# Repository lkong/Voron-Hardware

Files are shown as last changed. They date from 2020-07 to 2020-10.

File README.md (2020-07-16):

# Voron-Hardware
Cool Hardware designed by the Voron Design group

| Project | Overview |  
|---|---|
| Hall Effect Endstop | Replacement for mechanical endstop switches with an adjustable magnetic endstop PCB |
| Klipper Expander | Standalone MCU for use with Klipper with various inputs and outputs |
| Nano Display | Adapts an Arduino Nano to the RepRap standard 2 2x5pin IDC Connectors |
| Taco Raven | 3D Printer controller with 8 integrated stepper drivers for use with Klipper |
| Toolhead Board | Remix of Klipper Expander to fit on a toolhead mounted to a nema17 or 40mm fan |

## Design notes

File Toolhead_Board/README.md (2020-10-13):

# STM32-Tool-Heade-Board

Image no work =(

Simple MCU board for use with Klipper 3D Printer firmware with:
 - STM32F042F6P6 MCU with internal oscilator
 - 4 Mosfet outputs (1 3A one for hotend, 3 for fans)
 - 2 Thermistor inputs
 - 1 GPIO header

 Parts that need to be sourced if assembled by JLC:
  - Micro USB port [Molex 105017-0001](https://www.digikey.com/product-detail/en/molex/1050170001/WM1399CT-ND/2350885) or equivalent [Amazon](https://www.amazon.com/gp/product/B01IQ8VN94)
  - Resettable Fuse [MF-R800](https://www.digikey.com/en/products/detail/bourns-inc/MF-R800/259980)
  - 2 Pin Tactile Switch [6 x 3.5mm Button](https://www.digikey.com/product-detail/en/c-k/PTS636-SP43-LFS/CKN12304-ND/10071717) or [Amazon](https://www.amazon.com/flashtree-3x6x4-3H-Momentary-Tactile-Button/dp/B083R566PK/ref=sr_1_13)
  - Screw Terminals [5.08mm Screw Terminals](https://www.digikey.com/product-detail/en/on-shore-technology-inc/OSTTA024163/ED2580-ND/614529)

To flash:
  1 Bridge BOOT1 with solder
  2 Flash
  3 disconnect BOOT1

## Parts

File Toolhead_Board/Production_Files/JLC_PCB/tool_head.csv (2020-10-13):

Id | Designator | Package | Quantity | Designation | Supplier and ref
1 | R9,R7,R8,R10 | R_0805_2012Metric | 4 | 100
2 | U1 | TSSOP-20_4.4x6.5mm_P0.65mm | 1 | STM32F042F6Px
3 | BOOT1 | R_0805_2012Metric | 1 | 0R
4 | R1,R2,R11,R12,R13,R14 | R_0805_2012Metric | 6 | 10K
5 | C1,C3 | C_0805_2012Metric | 2 | 0.1uF
6 | C2,C4 | C_0805_2012Metric | 2 | 4.7uF
7 | C5,C6 | C_0805_2012Metric | 2 | 10uF
8 | D1,D2,D3,D4,D5,D6,D7 | LED_0805_2012Metric | 7 | LED
9 | J1 | USB_Micro-B_Molex-105017-0001 | 1 | USB_B_Micro
10 | J3 | PinHeader_2x04_P2.54mm_Horizontal | 1 | Conn_02x04_Odd_Even
11 | J5 | 1x02_ScrewTerminal_Phoenix | 1 | Vin
12 | J6 | 1x02_ScrewTerminal_Phoenix | 1 | HotEnd
13 | J8 | JST_XH_B2B-XH-AM_1x02_P2.50mm_Vertical | 1 | Conn_01x02
14 | J12 | PinHeader_1x03_P2.54mm_Vertical | 1 | Conn_01x03
15 | R3,R21 | R_0805_2012Metric | 2 | 1K
16 | R15,R16,R17,R18,R19,R20,R22 | R_0805_2012Metric | 7 | 4.7K
17 | SW2 | 2PinTactileButton | 1 | SW_SPST
18 | U2 | SOT-23-5 | 1 | AP2127K-3.3
19 | F1 | Fuse_Littelfuse-LVR200 | 1 | Fuse
20 | J13,J14 | PinHeader_1x02_P2.54mm_Vertical | 2 | Conn_01x02
21 | Q1,Q2,Q3,Q4 | SOT-23 | 4 | IRLML6344TRPBF

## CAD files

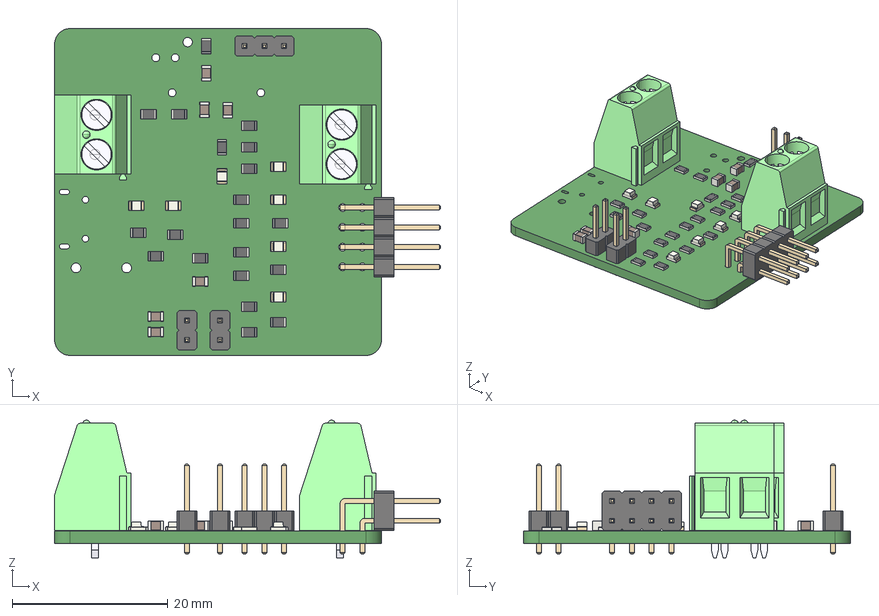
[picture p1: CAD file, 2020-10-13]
Toolhead_Board/CAD/tool_head.step
49.6 x 42.0 x 17.7 mm

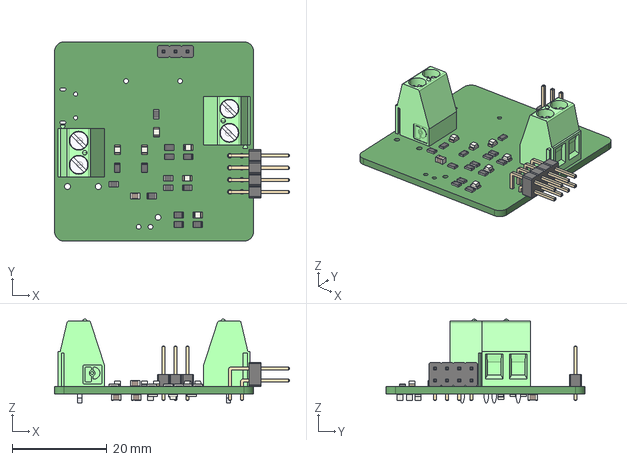
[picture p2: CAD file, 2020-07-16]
Toolhead_Board/KiCad/tool_head.step
49.6 x 42.0 x 17.7 mm

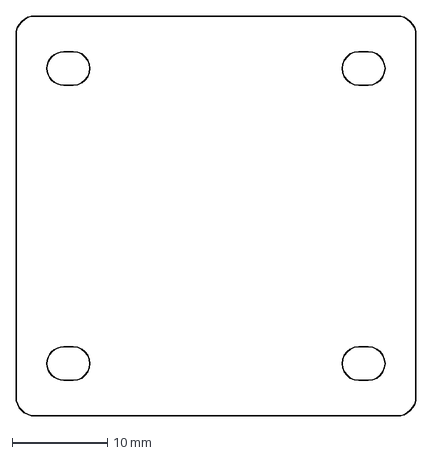
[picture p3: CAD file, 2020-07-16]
Toolhead_Board/CAD/toolhead_board.dxf
42.0 x 42.0 mm

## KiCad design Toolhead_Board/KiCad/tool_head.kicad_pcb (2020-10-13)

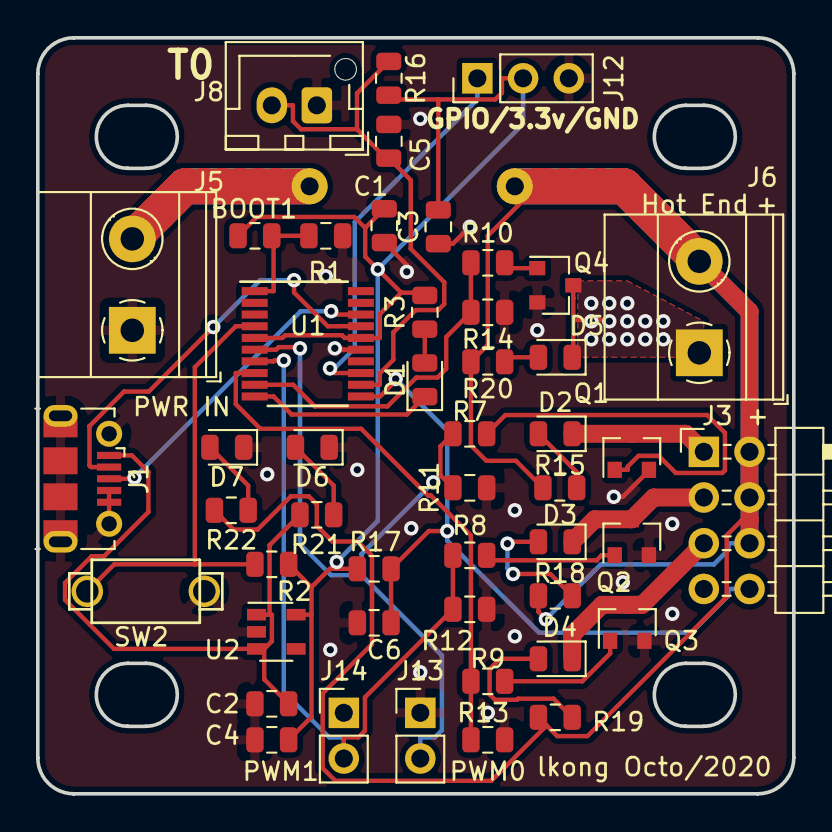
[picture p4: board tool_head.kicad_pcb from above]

Board: 2 copper layers, 42.0 x 42.0 mm, 49 parts (1 on the bottom side), 32 nets.

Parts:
BOOT1: 0R; R_0805_2012Metric
C1, C3: 0.1uF; C_0805_2012Metric
C2, C4: 4.7uF; C_0805_2012Metric
C5, C6: 10uF; C_0805_2012Metric
D1, D2, D3, D4, D5, D6, D7: LED; LED_0805_2012Metric
F1: Fuse; Fuse_Littelfuse-LVR200
J1: USB_B_Micro; USB_Micro-B_Molex-105017-0001
J3: Conn_02x04_Odd_Even; PinHeader_2x04_P2.54mm_Horizontal
J5: Vin; 1x02_ScrewTerminal_Phoenix
J6: HotEnd; 1x02_ScrewTerminal_Phoenix
J8: Conn_01x02; JST_XH_B2B-XH-AM_1x02_P2.50mm_Vertical
J12: Conn_01x03; PinHeader_1x03_P2.54mm_Vertical
J13, J14: Conn_01x02; PinHeader_1x02_P2.54mm_Vertical
Q1, Q2, Q3, Q4: IRLML6344TRPBF; SOT-23
R1, R2, R11, R12, R13, R14: 10K; R_0805_2012Metric
R3, R21: 1K; R_0805_2012Metric
R7, R8, R9, R10: 100; R_0805_2012Metric
R15, R16, R17, R18, R19, R20, R22: 4.7K; R_0805_2012Metric
SW2: SW_SPST; 2PinTactileButton
U1: STM32F042F6Px; TSSOP-20_4.4x6.5mm_P0.65mm
U2: AP2127K-3.3; SOT-23-5

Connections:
+3V3: BOOT1.2, C1.2, C3.2, C4.2, J12.2, R2.1, R3.2, R16.2, R17.2, U1.5, U1.16, U2.5
/BOOT0: BOOT1.1, R1.2, U1.1
/D+: J1.3, U1.18
/D-: J1.2, U1.17
/LED: D1.1, U1.10
/Mosfet0: D2.1, J3.1, Q1.3
/Mosfet1: D3.1, J3.3, Q2.3
/Mosfet2: D4.1, J3.5, Q3.3
/Mosfet3: D5.1, J6.1, Q4.3
/VBUS: C2.2, J1.1, R21.2, U2.1, U2.3
/Vin: F1.1, J3.2, J3.4, J3.6, J6.2, R15.1, R18.1, R19.1, R20.1, R22.2
/~RESET: R2.2, SW2.2, U1.4
GND: C1.1, C2.1, C3.1, C4.1, C5.1, C6.1, D6.1, D7.1, J1.4, J1.5, J1.6, J3.7, J5.1, J8.1, J12.3, J13.1, J14.1, Q1.2, Q2.2, Q3.2, Q4.2, R1.1, R11.2, R12.2, R13.2, R14.2, SW2.1, U1.15, U2.2
GPIO: J12.1, U1.13
unnamed: D1.2, R3.1
unnamed: D2.2, R15.2
unnamed: D3.2, R18.2
unnamed: D4.2, R19.2
unnamed: D5.2, R20.2
unnamed: D6.2, R21.1
unnamed: D7.2, R22.1
unnamed: F1.2, J5.2
unnamed: Q1.1, R7.2
unnamed: Q2.1, R8.2
unnamed: Q3.1, R9.2
unnamed: Q4.1, R10.2
PWM0: J13.2, R7.1, R11.1, U1.6
PWM1: J14.2, R8.1, R12.1, U1.7
PWM2: R9.1, R13.1, U1.8
PWM3: R10.1, R14.1, U1.9
T0: C5.2, J8.2, R16.1, U1.12
T1: C6.2, J3.8, R17.1, U1.11

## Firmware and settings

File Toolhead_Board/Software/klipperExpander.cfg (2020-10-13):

[mcu expander]
serial: /dev/serial/by-id/usb-Klipper_stm32f042x6_350022000D43504735393520-if00
restart_method: command

[output_pin mosfet0]
pin: expander:PA0
value: 0
shutdown_value: 0

[output_pin mosfet1]
pin: expander:PA1
value: 0
shutdown_value: 0

[output_pin mosfet2]
pin: expander:PA2
value: 0
shutdown_value: 0

[output_pin mosfet3]
pin: expander:PA3
value: 0
shutdown_value: 0

# Other Pins
# T0 = PA6
# T1 = PA5
# GPIO = PA7
#
